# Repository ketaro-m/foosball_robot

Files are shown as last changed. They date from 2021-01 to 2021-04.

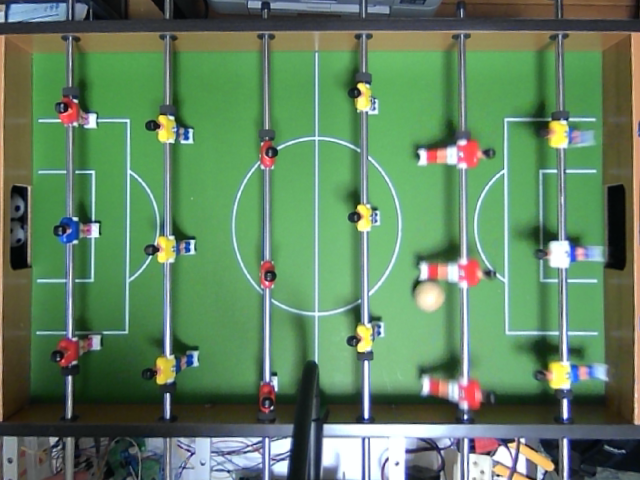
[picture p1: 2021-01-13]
img/board.png

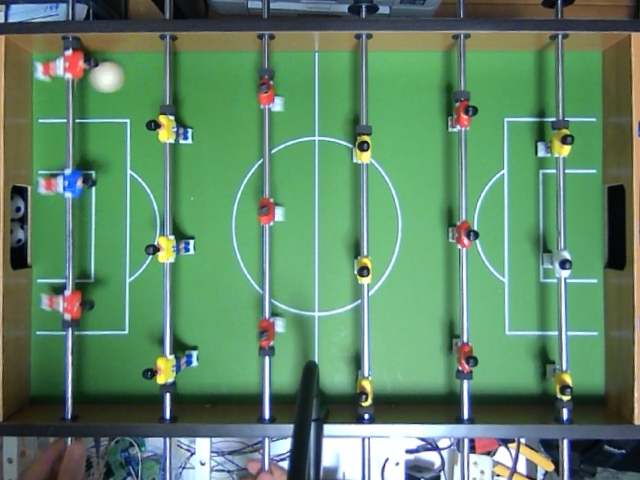
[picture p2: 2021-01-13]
img/board2.png

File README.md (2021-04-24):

# Foosball Robot
This is a vision controlled foosball table. The camera above the table processes the image and tracks the ball's position. The Arduino receives that information via ROS communication and control six stepper motors simultaneously; linear and rotation axes for three bars.



# Demo
Dome video is here. &rarr; https://youtu.be/knL-YN4Qc_c

# Environment

## Hardware
- [Arduino Mega 2560](https://store.arduino.cc/usa/mega-2560-r3)
- [L6470 stepper motor driver](https://www.st.com/en/motor-drivers/l6470.html) ([datasheet](https://www.st.com/resource/en/datasheet/l6470.pdf))  
... details are on [the report](https://github.com/ketaro-m/foosball_robot/blob/main/docs/report.pdf)

### Circuit diagram

## Software

- Ubuntu 18.04
- ROS Melodic Morenia

### ROS packages

- [uvc_camera](http://wiki.ros.org/uvc_camera)
- [usb_cam](http://wiki.ros.org/usb_cam) &larr; use this package instead of uvc_camera if uvc_camera doesn't support your camera driver's pixel format.
- [camera_calibration](http://wiki.ros.org/camera_calibration)
- [image_proc](http://wiki.ros.org/image_proc)
- [cv_brigde](http://wiki.ros.org/cv_bridge)
- [opencv_apps](http://wiki.ros.org/opencv_apps)
- [rosserial](http://wiki.ros.org/rosserial) (See [*Appendix A*](#appendix-a:-installing-rosserial) for installation)
- [rqt_image_view](http://wiki.ros.org/rqt_image_view)
- ([Joy](http://wiki.ros.org/joy)) &larr; Joy stick controll mode (see [joy branch](https://github.com/ketaro-m/foosball_robot/tree/joy))

### System diagram


# 1. Camera Calibration

## ROS Wiki
- [camera_calibration](http://wiki.ros.org/camera_calibration)
- [How to Calibrate a Monocular Camera](http://wiki.ros.org/camera_calibration/Tutorials/MonocularCalibration)

First, download the checker board ([check_7x6_27mm.pdf](http://wiki.ros.org/turtlebot_kinect_arm_calibration/Tutorials/CalibratingKinectToTurtleBotArm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)) and run the calibration program. Move the checker board around in the camera view.

```bash
$ ls /dev/ | grep video # check the device name

# run calibration programs (in different terminals)
$ roscore
$ rosrun uvc_camera uvc_camera_node _device:=/dev/video1
$ rosrun camera_calibration cameracalibrator.py --size 7x6 --square 0.027 image:=/image_raw
```

 

Then extract the gz file and place the yaml file in the appropriate directory.

```bash
# make camera.yaml
$ mkdir camera_calibration; cd camera_calibration
$ mv /tmp/calibrationdata.tar.gz ./
$ tar -xvzf calibrationdata.tar.gz
$ mv ost.yaml camera.yaml
$ vi camera.yaml 
# rewrite "camera_name: narrow_stereo" -> "camera_name: camera", 
#         "camera_model: plumb_bob" -> "distortion_model: plumb_bob"
```

Finally, check the result

```bash
$ roscore
$ rosrun uvc_camera uvc_camera_node _device:=/dev/video1 _camera_info_url:=file://$PWD/camera_calibration/camera.yaml
$ rosrun image_proc image_proc
$ rqt_image_view
```

or run this launch file (yet, need to modify the absolute path to camera.yaml in line 4)

```bash
$ roslaunch launch/calibration_demo.launch # use "calibration_demo_usb.launch" instead for usb_cam package 
```

  

# 2. Ball Tracking

### 1. Check the pixels of the fields.

After establishing the camera nodes, open rqt_image_view and select /image_rect_color. Then click the top-left and bottom-right points and check their pixel x, y values with echoing /image_rect_color_mouse_left.

```bash
$ roslaunch launch/track_ball.launch # use "track_ball_usb.launch" instead for usb_cam package
$ rqt_image_view # select /image_rect_color
$ rostopic echo /image_rect_color_mouse_left
```
Fill these values in `scripts/hsv.py` and `scripts/track_ball_demo.py`.

```Python
field_area = [[33, 50], [605, 405]] # [[top-left x,y], [bottom-right x, y]]
```

### 2. Optimize HSV value

In order to track only the ball, you have to optimize the HSV value of the mask filter.  
To do so, save a camera view image using the save button of the rqt_image_viewer, and run `scripts/hsv.py` with the image.

```bash
$ python scripts/hsv.py [image file name]
```
Click the ball in the "hsv" image window, and check the HSV value which is printed on the terminal. 

 
<br />

Lastly, to check if the ball is correctly tracked, fill the hsv_lower and hsv_upper values obtained above and run `scripts/track_ball_demo.py`. Looking at the result, you might have to modify hsv values and filter sizes of image processings.

(track_ball_demo.py)

```Python
# obtain from hsv.py
hsv_lower = np.array([20, -10, 100])
hsv_upper = np.array([50, 64, 300])
median_size = 7      # filter size for median filter
morpho_size = 13     # filter size for morphology processing
```
In terminal, run the following commands.

```bash
$ roslaunch launch/track_ball.launch
$ python scripts/track_ball_demo.py
```

 

### 3. Publishing ROS topic
Finally, publish the ball position as a ROS topic, which will be subscribed by the Arduino. `scripts/ball_position_publisher.py` conducts the entire image processing of the previous sections and publishing ROS topic `/ball_position (opencv_apps/Circle)`. This script will be used as the final form of this section.  
Fill the parameters in line 11~18 and confirm that the ball position is correctly published.

```bash
$ roslaunch launch/track_ball.launch # use "track_ball_usb.launch" instead for usb_cam package
$ python scripts/ball_position_publisher.py
$ rostopic echo /ball_position
```

# 3. Let's play!
Now you've prepared all pieces. Kickoff is almost there!  

After writing "sketchbook/L6470_SPI_stepMoter_sketch/L6470_SPI_stepMoter_sketch.ino" into the Arduino Mega, launch the uvc_camera node and rosserial node by the following command.

```bash
$ roslaunch launch/stepper_camera_driver.launch # use "stepper_camera_driver_usb.launch" instead for usb_cam package
```
Once the nodes have been successfully launched, the motor positions will be initialized like this.

 

The last thing you have to do is launching the image processing node. If you start running this program, the whole ROS pipeline is established and the robot starts moving.

```bash
$ python scripts/ball_position_publisher.py
```
Enjoy fighting!

 

# Appendix
## *Appendix A: Installing rosserial*

First, you need to install the ros packages.

```bash
$ sudo apt install ros-melodic-rosserial
$ sudo apt install ros-melodic-rosserial-arduino
```

Second, go to the *libraries* directory below the installed Arduino folder, and run the following setup script which is given by the rosserial package.

```bash
$ cd ~/arduino-1.8.13/libraries
$ rosrun rosserial_arduino make_libraries.py .
$ ls | grep ros_lib  # check if it's successfully installed
ros_lib
```

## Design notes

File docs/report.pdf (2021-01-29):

## Foosball Robot

## 03-190294 村上 恵太郎

01/29/2021

## 1 概要

Foosball(通称テーブルサッカー) の対戦相手となるロボットを制作した．Web カメラで読み込んだ画像からボー ルの位置を認識し，その結果に基づいてモータを制御してバーを動かしている．以下にデモ動画を作成した．

✓ | ✏
https://youtu.be/knL-YN4Qc_c ✒ | ✑
✓ また，完成したソースコードは以下のリポジトリに置いてある． | ✏
https://github.com/ketaro-m/foosball_robot ✒ | ✑

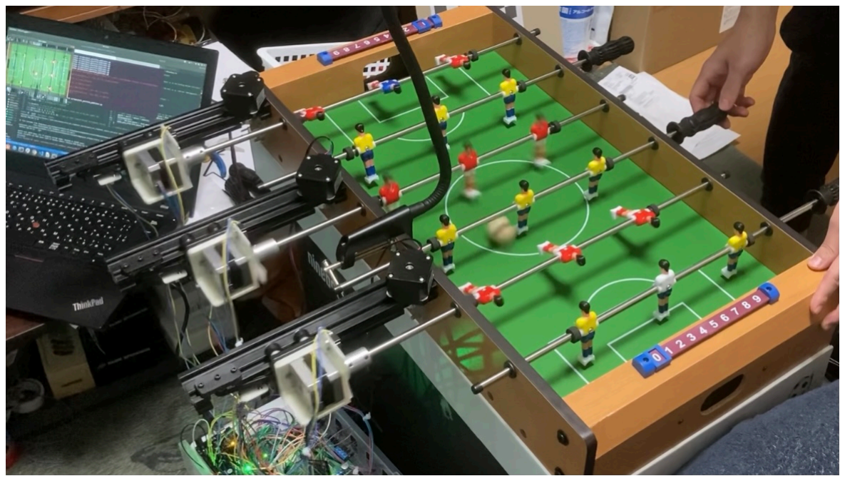
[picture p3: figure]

図 1: 作品の全体像

## 2 実行環境

### 2.1 ハードウェア

ハードウェアは補遺 A に記載した部品表のものを使用した．

### 2.2 ソフトウェア

- Ubuntu 18.04
- ROS Melodic Morenia

ROS packages

- uvc camera (http://wiki.ros.org/uvc_camera)
- camera calibration (http://wiki.ros.org/camera_calibration)
- image proc (http://wiki.ros.org/image_proc)
- cv bridge (http://wiki.ros.org/cv_bridge)
- rosserial (http://wiki.ros.org/rosserial)
- rqt image view (http://wiki.ros.org/rqt_image_view)

## 3 動作原理

台の真上に設置した Web カメラで盤面の画像を読み込み，色抽出をベースとした画像処理を施すことによって ボール位置を認識し，その結果を Arduino が受け取って 6 つ (3 つのバーそれぞれにつき並進と回転) のステッピ ングモータを制御することによってボールを打ち返す．これを 10 fps のサイクルで繰り返すことによって，ボー ルに素早く追従する．
この全体像を ROS ノードの構成図で表すと以下のようになる．

図 2: ROS ノード

## 4 動作結果

まず，L6470 SPI stepMoter sketch.ino (https://github.com/ketaro-m/foosball_robot/blob/main/sketchbook/L6470_SPI_stepMoter_sketch/L6470_SPI_stepMoter_sketch.ino) をArduinoに書き込む．次に，以下にあるように launch/stepper camera driver.launch (https://github.com/ketaro-m/foosball_robot/blob/main/launch/stepper_camera_driver.launch) を実行してカメラノードなどの複数の ROS ノードを立ち上げた後，最後に scripts/ball position publisher.py (https://github.com/ketaro-m/foosball_robot/blob/main/scripts/ball_position_publisher.py) を
✓
実行して画像処理ノードを立ち上げると，図 2 にあるようなパイプラインが繋がって全体が動くようになる．

✏

$ roslaunch launch/stepper camera driver.launch
$ python scripts/ball position publisher.py
✒ | ✑

## 5 制作過程

### 5.1 ハードウェア設計

既製品の Foosball 台を使用し，それに合うように部品を選定して組み合わせた．リニアモジュールとステッピ ングモータを接続する部分，ゼロ点 (モータ制御のセクションで説明する) 用のマイクロスイッチを取り付ける部 分は 3D プリンタを用いて作成した．

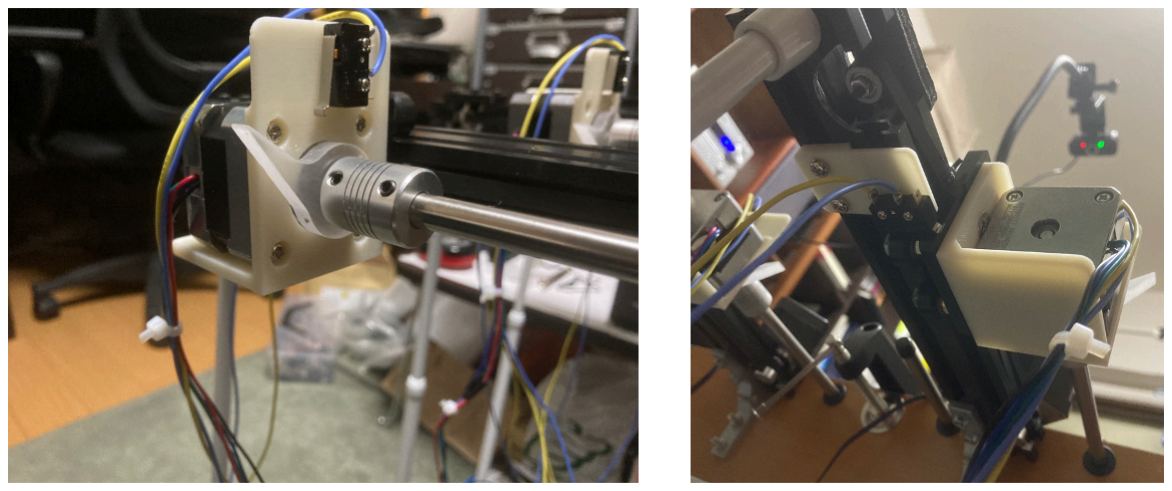
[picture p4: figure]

図 3: 3D プリンタで作成した部品

### 5.2 画像処理

### 5.2.1 カメラキャリブレーション

Web カメラから直接入ってくる画像にはレンズ歪みがあるので，これを補正する内部パラメータを求める必要が ある．このためのプログラムは用意されているため，以下のサイトに従ってチェッカーボードをカメラの前で動か すことで，画像のように補正することができる．詳細な手順は，README.md(https://github.com/ketaro-m/

foosball_robot/blob/main/README.md) (https://github.com/ketaro-m/foosball_robot/blob/main/README.md) に記載している．

- camera calibration (http://wiki.ros.org/camera_calibration)
- How to Calibrate a Monocular Camera (http://wiki.ros.org/camera_calibration/Tutorials/

MonocularCalibration) (http://wiki.ros.org/camera_calibration/Tutorials/MonocularCalibration)

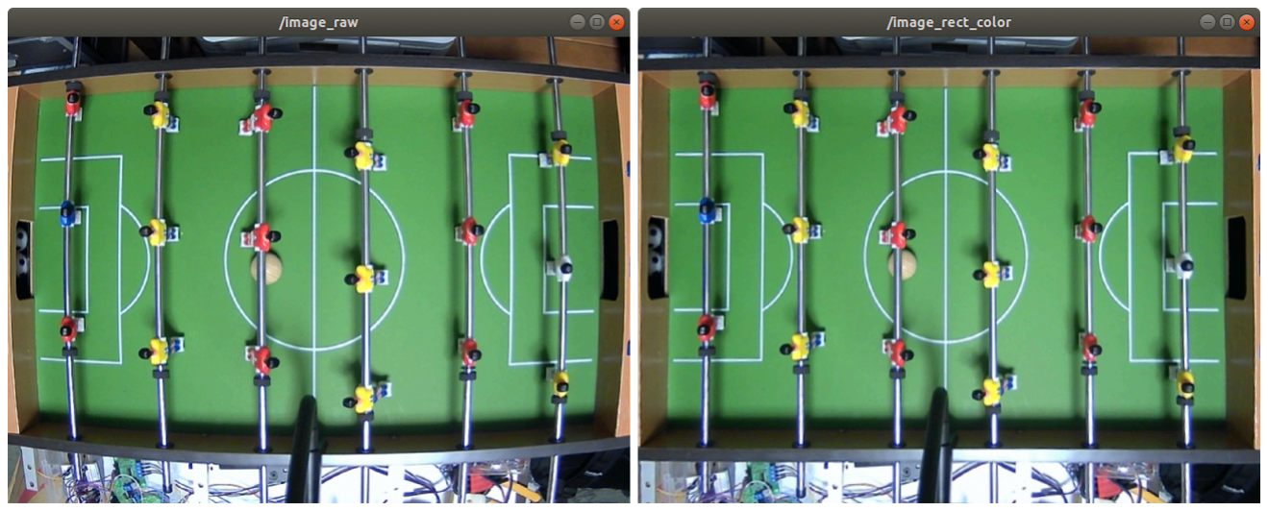
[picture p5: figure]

図 4: キャリブレーション結果

### 5.2.2 ボール検出

ボールの検出には HSV カラーフィルタを用いる．
画像処理の一連の流れは以下の画像の通りで，まず初めにフィールド内 (画像内でのフィールドのピクセルは事前 に設定しておく) に HSV フィルターをかけ，特定の HSV 値の領域を抽出する．次に，メジアンフィルタ，膨張・ 収縮処理を施すことによって，ノイズ除去とボール領域のクロージングを行う．最後に画像中の最大領域を取得す ることによって，ボールの領域のみを検出する．

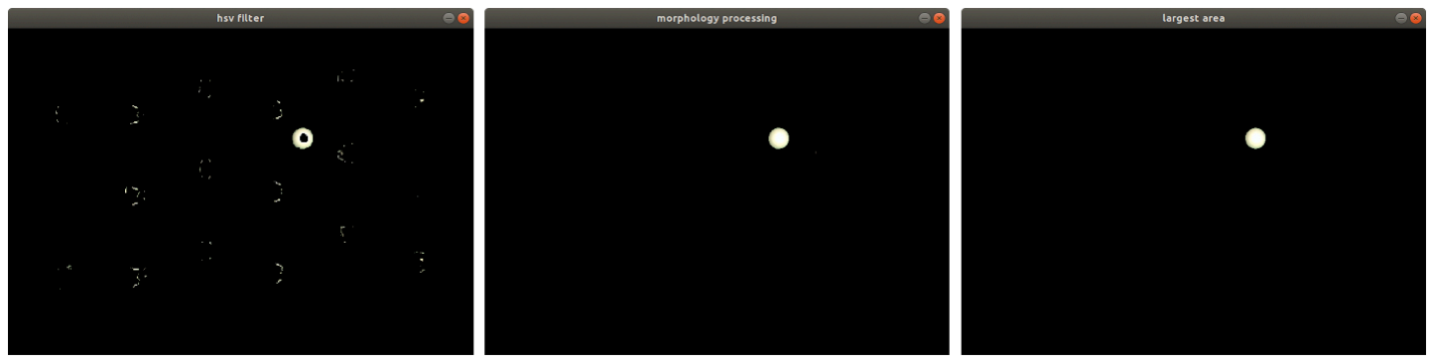
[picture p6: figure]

図 5: 画像処理

ボールの HSV 値は適切に設定しておく必要がある．しかし，環境によって光の当たり具合が若干異なり適切な HSV 値が変わってしまうため，このチューニング用のプログラムも作成した． カメラノードを立ち上げた状態で script/hsv.py (https://github.com/ketaro-m/foosball_robot/blob/main/scripts/hsv.py) を実行すると画像が表示され，ボールをクリックするとそのピク セルの HSV 値が得られる．このプロセスを何回か行ったり，ボール内の様々なピクセルを選択することで，適切

な HSV 値の領域をチューニングする．
この値を scripts/ball position publisher.py (https://github.com/ketaro-m/foosball_robot/blob/main/scripts/ball_position_publisher.py) のプログラム上部に設定して以下のようにプログラムを立ち上げる と，画像のように適切にボール位置を検出することができていることが分かる．また，このプログラムはその座 標を ROS トピック (/ball position (opencv apps/Circle 型)) として publish する役割も担っている．

こちらも，詳細な手順は，README.md(https://github.com/ketaro-m/foosball_robot/blob/main/README.

md (https://github.com/ketaro-m/foosball_robot/blob/main/README.md)

✓
) に記載している．

✏

$ roslaunch launch/track ball.launch
$ python scripts/ball position publisher.py
$ rostopic echo /ball position
✒ | ✑

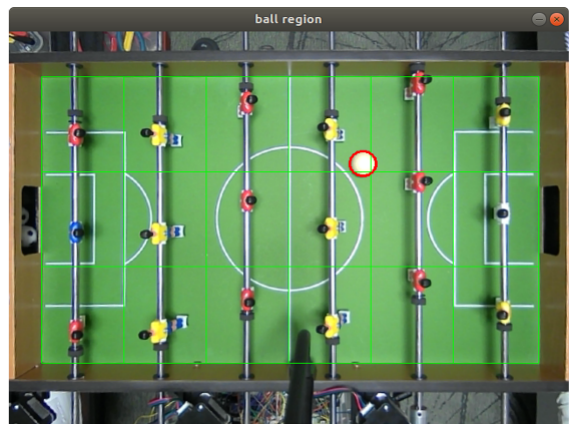
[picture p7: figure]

図 6: 検出結果

### 5.3 モータ制御

ステッピングモータの制御には，L6470 というチップの乗ったモータドライバを使用した．SPI 通信という方 式が取られ，8bit ごとにデータを区切って送信することで，データシート (https://www.st.com/resource/en/datasheet/l6470.pdf) (https://www.st.com/resource/en/datasheet/l6470.pdf) に載っている様々なコマンドを送って制御できる．これを実現する Arduino スケッチの

ライブラリは，このブログ (http://spinelify.blog.fc2.com/blog-entry-41.html) に載っているものを使用 した．
複数のモータを制御するためには，モータドライバをデイジーチェイン接続する必要がある．デイジーチェイン接続

とは，図 7 にあるように (このブログ (https://garchiving.com/control-multiple-motors-with-arduino/) から引用した)，複数 byte を順々に押し出してそれぞれのモータドライバに所望の byte 値を書き込む方式である． このデイジーチェイン接続を考慮した複数モータの制御ライブラリは存在しなかったため，上述のライブラリを 参考にしながら，全てのライブラリを書き直す作業を要した．これにより，デイジーチェインという直列の通信方 法であっても，Arduino スケッチのメインプログラム内では，特定のモータのみを特定のコマンドで駆動するよ うな形式でプログラムできるようにした．
今回の作品ではモータをデフォルト値よりもかなり高速に動かす必要があった．これはモータドライバのあるレ ジスタ値を設定することで実現できるのだが，その値に伴って電圧値も適切に設定する必要があった．また，モー タを速く動かしすぎると脱調を起こしてしまう．これを防ぐためにも，各種レジスタ値をチューニングし，加速度 やその立ち上がりの角度を適切に設定する作業が必要であった．この適切な値はモータの数を増やす度に若干変 更されるため，その都度チューニングする必要があった． どうしても脱調を起こしてしまうことは防ぎきれず自己位置がずれてしまう，また，ボールがプレイヤーに強く当 たるとモータが逆方向に回転してずれてしまう．これを補正するためには，図 3 にあるようにマイクロスイッチに よるゼロ点を用意した．原理としては，脱調が検出されたら，そのモータを脱調復帰モードに切り替えてマイクロ

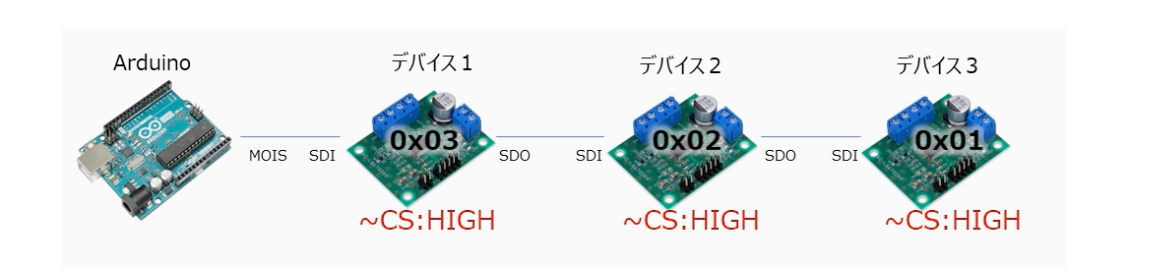
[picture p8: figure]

図 7: デイジーチェイン接続

スイッチが押される位置まで動かし，押された瞬間にモータドライバの位置レジスタの値を所定の値にリセットす るというメカニズムである．また，脱調検出がされなくても，スイッチが押される位置にモータが来たときは位 置をリセットし，自己位置がずれてしまったが脱調検出がなされなかった場合にも定期的に修正するようにした． 脱調とは，モータが機械的に入力パルスに追従できず，ストール (失速) する現象である．これは，モータの起電 力という形で電気的に検出でき，今回使用したモータドライバにはエラー検知用のレジスタという形で組み込ま れていた．よって，これらを Arduino の入力ピンに結線して監視することで，脱調検出を可能とした．この検出 判定の閾値などのパラメータは，何回か試してみて決定する必要があった．

Arduino スケッチの概要

- L6470 SPI stepMoter sketch.ino (https://github.com/ketaro-m/foosball_robot/blob/main/sketchbook/L6470_SPI_stepMoter_sketch/L6470_SPI_stepMoter_sketch.ino) ← メインプログラム
- L6470 commands.ino (https://github.com/ketaro-m/foosball_robot/blob/main/sketchbook/L6470_SPI_stepMoter_sketch/L6470_commands.ino) ← モータコマンドライブラリ
- L6470 commands multi.ino (https://github.com/ketaro-m/foosball_robot/blob/main/sketchbook/L6470_SPI_stepMoter_sketch/L6470_commands_multi.ino) ← モータコマンドライブラリ (デイジーチェイン対応)
- foosball commands.ino (https://github.com/ketaro-m/foosball_robot/blob/main/sketchbook/L6470_SPI_stepMoter_sketch/foosball_commands.ino) ← ゲーム操作コマンドのライブラリ

メインプログラム (L6470 SPI stepMoter sketch.ino) は，同じディレクトリ内にあるライブラリをインポートす る形で利用している．まずセットアップでは，各種ピンの設定，SPI 通信の立ち上げ，ROS ノードの立ち上げな どを行い，メインループの中で恒常的に脱調検出ピン，ゼロ点ピンの監視を行っている．さらに，画像処理ノー ドによって publish されたボール位置を subscribe しており，その結果に基づいたコマンド操作をして，バーを操 縦している．
バー操縦のコマンドは比較的シンプルで，まず，図 6 にあるようにフィールドを分割することで，ボールが相手 側にあるか自分側にあるかを判別し，相手側にあった場合はディフェンス，自分側にあった場合はオフェンス動 作をする．ディフェンスの場合は，横方向はボール位置に追従するようにスライドし，ボールよりも後ろにいる プレイヤーは足でボールを止められるようにバーを回転する．ボールよりも前のプレイヤーは攻撃に備えて足を あげておく．オフェンスの場合は，ボール位置にいるバーはキックモーションを行い，それよりも後ろはディフェ ンスと同じ要領で防御の構えをし，それよりも前にいるバーは後ろから来るボールの通路を空けるように構える． 基本的にはこのようなコマンドは全てモータの回転角を指定することで実現でき，ボール位置の publish と同じ周 波数，つまり 10 fps でモータの回転角を上書きしていくようなサイクルで指示を出していくが，キックモーショ ンは 1 回のサイクルよりも長いサイクルを要する．この場合や，脱調検出がされたことによって脱調復帰モードに なっているモータには指示がいかないように，特定のモータにだけコマンド指示が送られるように工夫した．具 体的には，グローバル変数として 6bit の変数を用意し，各 bit にそれぞれのモータの状態フラグを表現して，そ の情報も含めてモータに指示が送られるように工夫した．各モータフラグを配列として表現するとポインタの受 け渡しなどが煩雑になったが，このように int 型の変数を 2 進数と見なして受け渡すことで，プログラムを簡潔に したり，メモリの節約をすることができた．

## 6 苦労したこと，反省，感想

スターリングエンジン設計演習を通して機械設計や加工は経験したが，ソフトウェアや電子部品も含めて一人 で設計する経験はほとんど初めてだった．自分で加工した部品は少ないが，データシートを正しく読み，適切な 部品を選定する過程は非常にためになった．
ハードウェアを含んだものだと，理論上は正しく動くはずでも実機では動作しないということが多々起こり，ま たそのデバッグも大変だった．例えば，モータを複数に増やすと電圧・電流が足りなくなって動作をしなくなる， Arduino Nano ではメモリが少なく，ROS ノードを立てるような処理を加えるとメモリが圧迫されて動作が不安 定になる，といったバグは発見するまでに時間を要した．しかし，理論を学んだだけでは気づけないようなバグ を身を持って体験できたのは貴重な経験だったと思う．
この制作過程で最も大変だったのは，複数のモータを適切に制御することだった．特に，今回は非常に素早く動 かす必要があったので，モータの特性から考えて各種のパラメータを調整する過程が大変だった．また，複数の モータにした途端に動かなくなったり，計算のオーバーフローが起きていたり，突き詰めていけば必ずどこかに特 定の原因があるものだが，それを見つけるまでに多くの時間を費やしてしまった．しかしながら，こうしたエラー は体系的に学べるものではなく，このように逐一経験していくことでしか学べないので，今後の糧になると思う． 当初の題目は「FC DQN」であったように，目標は強化学習を用いてモータ制御も学習させることだったが，上 述のモータ制御に時間がかかってそこまで辿り着くことはできなかった．モータ制御のセクションで説明したよ うなルールベースのプログラムでも対戦相手としては楽しめるものになったし，1ヶ月強の制作期間で作るものと しては及第点だと思うが，せっかくなら学習にも着手したかった．この辺りは，制作のスケジュールの問題であ り，反省して次に活かせるポイントである．例えば，部品の発注は到着するまでに時間がかかるから早めに済ま すなどの優先順位をつけることはもちろん，期限までに小さなマイルストーンを置き，小さなステップに分解し ながら進めることで進捗管理やプラン B への切り替え判断を迅速にするなどの工夫も必要だと感じた．この辺り は，エンジニアリングの世界では重要なことであると思うので，今後に生かしていきたい．

### お願い

総じて自主プロは非常に良いプログラムだと思いますが，費用の全てが学生の自己負担であることは，この演 習の唯一の欠点だと思います．僕が上述のように経験できたデバッグ作業は，ハードウェアを積極的に使うことで 得られるものであるし，僕もその観点から費用を捻出することにためらいはなかっのびですが，金銭的な問題か ら制作物を制限してしまう学生も少なからずいるのではないかと思います．少額であっても学生の学びの質を高 めることになり，自主プロがより良い演習になると思うので，制作費用の支援の検討をしていただければ後輩の ためになると思います．

謝辞

オンラインという難しい状況の中，多くの先生方のご協力のもと，この作品を完成させることができました． コンセプト段階から相談に乗っていただけた岡田先生，モータ制御や機械設計についてアドバイスをくださった 浅野先生，3D プリンタの印刷を手伝っていただいた西川先生には特に感謝を申し上げます． その他，相談に乗ってくださった先生方，学科同期の皆さん，ありがとうございました．

## 補遺 A 部品表

以下に使用した部品の一覧を記載する．(部品名にハイパーリンクを付与している．)

部品名 | 個数
Foosball 台 (https://blog.jp.flyingtiger.com/item/zebrajapan-flyingtigercopenhagen-1600421636936-apparelcloud.productclass-5a3e3637-a5a9-4a0c-a2f3-f4ed53f3d1e7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) | 1
木球 | 1
ThinkPad (学科 PC) | 1
Arduino Mega (https://store.arduino.cc/usa/mega-2560-r3) | 1
AC アダプタ (24V 2.7A) (https://akizukidenshi.com/catalog/g/gM-06962/) | 1
DC ジャック端子変換 (https://akizukidenshi.com/catalog/g/gC-08849/) | 1
ブレッドボード，各種ジャンパピン
ステッピングモータリニアモジュール (https://www.banggood.com/HANPOSE-HPV2-Linear-Guide-Set-Openbuilds-V-Linear-Actuator-Effective-Travel-100-400mm-Linear-Module-with-17HS3401S-Stepper-Motor-p-14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) | 3
ステッピングモータ 42SHD4002-24B (https://akizukidenshi.com/catalog/g/gP-14604/) | 3
L6470 ステッピングモータドライバ (https://akizukidenshi.com/catalog/g/gK-07024/) | 6
M3×6 ねじ (ステッピングモータ固定用) | 12
カップリング (https://www.amazon.co.jp/-/en/gp/product/B07JL1QYLS/ref=ppx_yo_dt_b_asin_title_o00_s00?ie=UTF8&psc=1) | 3
ブラケット (https://www.monotaro.com/p/2173/7494/) | 3
M5 六角ナット, (https://www.monotaro.com/p/0552/8722/) ワッシャー (https://www.monotaro.com/p/0552/9772/) | 3
M5×20 皿木ネジ (F oosball 台とリニアモジュールの接続用) | 3
M5×8 皿頭小ねじ (リニアモジュールと 3D プリンタ部品の接続用) (https://www.monotaro.com/p/0550/8711/) | 12
マイクロスイッチ (https://akizukidenshi.com/catalog/g/gP-14659/) | 6
M2×12 ねじ，ナット (マイクロスイッチ固定用) | 12
M4×10 ねじ (マイクロスイッチ台座固定用) | 6
M3×6 いもねじ (ステッピングモータ軸と 3D プリンタ部品の固定用) | 6
USB カメラ (https://www.amazon.co.jp/-/en/Network-Computer-Flexible-Recording-Conference/dp/B08F7TR97T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) | 1
カメラスタンド (https://www.amazon.co.jp/-/en/Webcam-Adjustable-Tabletop-Camera-Logitech/dp/B071P5QRQ1) | 1

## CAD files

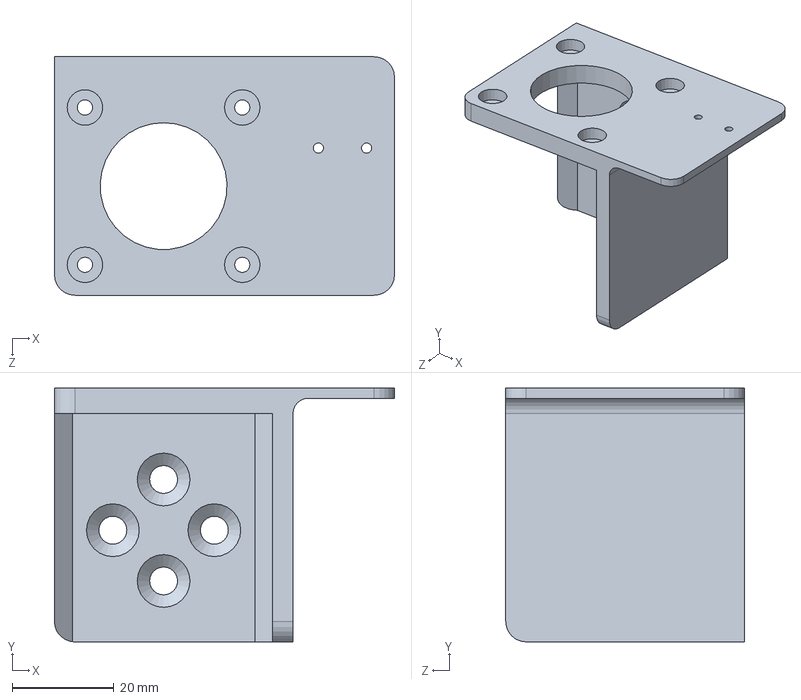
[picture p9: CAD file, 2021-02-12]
cad/stepper_bracket_v2.SLDPRT
67.0 x 50.0 x 47.0 mm

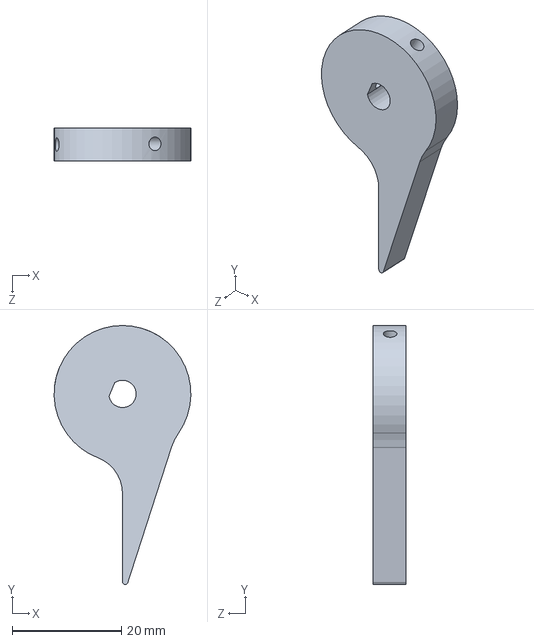
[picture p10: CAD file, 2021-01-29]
cad/pin_v3.SLDPRT
25.0 x 47.3 x 6.00 mm

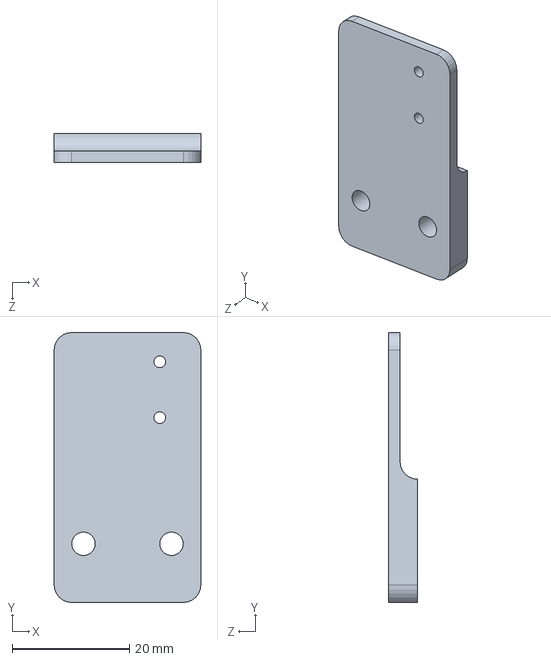
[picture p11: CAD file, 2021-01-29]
cad/switch_base.SLDPRT
25.0 x 46.0 x 5.00 mm

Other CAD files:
cad/stepper_bracket.SLDPRT
cad/pin_v3.STL
cad/stepper_bracket.STL
cad/stepper_bracket_v2.STL
cad/switch_base.STL

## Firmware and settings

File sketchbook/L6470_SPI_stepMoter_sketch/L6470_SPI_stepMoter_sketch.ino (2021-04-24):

#include <SPI.h>
#include <ros.h>
#include <opencv_apps/Circle.h>
#include <std_msgs/Int32MultiArray.h> // to publish pin values
ros::NodeHandle nh;
// #include "L6470_commands.ino"
// #include "L6470_commands_multi.ino"
// #include "foosball_commands.ino"

// number of motors
#define N 6
// define pins
#define PIN_SPI_MOSI 51
#define PIN_SPI_MISO 50
#define PIN_SPI_SCK 52
#define PIN_SPI_SS 53
#define PIN_BUSY 9
const int ERROR_PIN[N] = {2,3,4,5,6,7}; // digital pins
const int RESET_PIN[N] = {54,55,56,57,58,59}; // analog pins A0,...,A5 
const int PSEUDO_ERROR_PIN[3] = {62, 63, 64}; // manually trigger error recovery motionn
// parameters according to this machine environment
int ROT = 200*pow(2, 7); // steps per 1 rotation
int STROKE = 40; // stroke[mm] per 1 rotation

long param[N]; // array to get and store register values such as abs_pos, speed, etc.
/* position array to control motors */
long pos[N] = {0, 0, 0, 0, 0, 0};
long pos_copy[N] = {0, 0, 0, 0, 0, 0}; // copy pos because distang2pos change its values.
uint8_t non_error_motors = 0b111111; // mth bit is 0 if the mth motor steps out
uint8_t error_motion = 0b000000; // if mth motor is in error recovery motion or not (in order to avoid double command sending)
// long error_recovery_speed = 0x6000; // motor speed of error recovery motion.
long error_recovery_speed[N] = {0x6000, 0x6000, 0x6000, 0x3000, 0x3000, 0x3000}; // motor speed of error recovery motion.
long reset_pos[N] = {0, 0, 0, 0, 0, 0}; // set positions when the reset pin is pushed.
long reset_pos2[N] = {5, 5, 5, 10, 10, 10}; // positions to move just after touching reset pin in order to avoid touching pins forever

void stepper_cb(const opencv_apps::Circle& msg);
ros::Subscriber<opencv_apps::Circle> stepper_sub("ball_position", stepper_cb);
std_msgs::Int32MultiArray stepper_msg;
ros::Publisher stepper_pub("stepper", &stepper_msg);


void stepper_setup() {
  stepper_msg.data_length = N*3 + 2;
  stepper_msg.data = (int32_t *)malloc(sizeof(int32_t)*(N*3+2));
  for (int i = 0; i < N*3+2; i += 1) {
    stepper_msg.data[i] = 0;
  }

  nh.subscribe(stepper_sub);
  nh.advertise(stepper_pub);
}

/* publish the motors' state [abs_pos*6, error_pin*6, reset_pin*6, ball_position(x,y)] */
void stepper_publish_loop() {
  L6470_getparam_abspos(param, N);
  pos2distang(param);
  for (int i = 0; i < N; i += 1) {
    stepper_msg.data[i] = param[i];
    stepper_msg.data[i+N] = digitalRead(ERROR_PIN[i]);
    stepper_msg.data[i+N*2] = digitalRead(RESET_PIN[i]);
  }
  stepper_pub.publish(&stepper_msg);
}

/* subscribe ball_position and control stepper motors 
command() is in foosball_commands.ino. */
void stepper_cb(const opencv_apps::Circle& msg) {
  command((long)msg.center.x, (long)msg.center.y);
}

void setup()
{
  distang2pos(reset_pos);
  distang2pos(reset_pos2);
  // delay(1000);
  nh.initNode();
  stepper_setup();

  pinMode(PIN_SPI_MOSI, OUTPUT);
  pinMode(PIN_SPI_MISO, INPUT);
  pinMode(PIN_SPI_SCK, OUTPUT);
  pinMode(PIN_SPI_SS, OUTPUT);
  pinMode(PIN_BUSY, INPUT);
  for (int i=0; i<N; i+=1) {
    pinMode(ERROR_PIN[i], INPUT);
    /* use RESET PINs (analog pin) as digital pull down pins. */
    pinMode(RESET_PIN[i], OUTPUT);
    digitalWrite(RESET_PIN[i], HIGH);
  }
  // pseudo error pins
  for (int i=0; i<3; i+=1) {
    pinMode(PSEUDO_ERROR_PIN[i], OUTPUT);
    digitalWrite(PSEUDO_ERROR_PIN[i], HIGH);
  }
  //
  SPI.begin();
  SPI.setDataMode(SPI_MODE3);
  SPI.setBitOrder(MSBFIRST);
  digitalWrite(PIN_SPI_SS, HIGH);
 
  L6470_resetdevice(N); //reset all motors
  L6470_setup(0b111111);
  delay(3000);
  initial_setup();
}

unsigned long publish_timer = 0;
void loop(){
  unsigned long now = millis();

  if ((now - publish_timer) > 100) {
    stepper_publish_loop();
    publish_timer = now;
  }

  nh.spinOnce();
  delay(1);

  check_reset_pin();
  check_error_pin();
}

/* setup motors. */
void L6470_setup(uint8_t motors){
  long acc[N] = {0x500, 0x500, 0x500, 0x500, 0x500, 0x500};
  long dec[N] = {0x500, 0x500, 0x500, 0x500, 0x500, 0x500};
  long maxspeed[N] = {0x100, 0x100, 0x100, 0x100, 0x100, 0x100};
  long kvalhold[N] = {0x10, 0x10, 0x10, 0x80, 0x80, 0x80};
  long kvalrun[N] = {0x10, 0x10, 0x10, 0x80, 0x80, 0x80};
  long kvalacc[N] = {0x10, 0x10, 0x10, 0x80, 0x80, 0x80};
  long kvaldec[N] = {0x10, 0x10, 0x10, 0x80, 0x80, 0x80};
  L6470_setparam_acc(motors, N, acc);
  L6470_setparam_dec(motors, N, dec);
  L6470_setparam_maxspeed(motors, N, maxspeed);
  L6470_setparam_minspeed(motors, N, 0x01);
  L6470_setparam_fsspd(motors, N, 0x3ff);
  L6470_setparam_kvalhold(motors, N, kvalhold);
  L6470_setparam_kvalrun(motors, N, kvalrun);
  L6470_setparam_kvalacc(motors, N, kvalacc);
  L6470_setparam_kvaldec(motors, N, kvaldec);
  L6470_setparam_alareen(motors, N, 0x30); // alarm enable, stall detection
  L6470_setparam_stallth(motors, N, 0xff); // threshold for error detection (need tuning)
  L6470_setparam_ocdth(motors, N, 0xf);

  L6470_setparam_stepmood(motors, N, 0x07); //default 0x07 (1+3+1+3bit) : 1/2^n*1.8[deg] = 1step 
} 


/* functions to change distance[mm] or angle[degree] to steps(pos)*/
long dist2pos(long distance) {
  return ROT * distance / STROKE;
}
long ang2pos(long angle) {
  return ROT * (angle) / 360;
}
long pos2dist(long position) {
  return position * STROKE / ROT;
}
long pos2ang(long position) {
  return (position) * 360 / ROT;
}
void distang2pos(long *distang) {
  for (int i = 0; i < N; i += 1) {
    if (i < 3) {
      distang[i] = dist2pos(distang[i]);
    } else {
      distang[i] = ang2pos(distang[i]);
    }
  }
}
void pos2distang(long *position) {
  for (int i = 0; i < N; i += 1) {
    if (i < 3) {
      position[i] = pos2dist(position[i]);
    } else {
      position[i] = pos2ang(position[i]);
    }
  }
}

/* return true if the N lease bits (pointing at N motors) of uint8_t flag contains at least one 1 value.
this is for not sending unnecessary nothing commands. */
boolean checkflag(uint8_t flag) {
  return (flag << (8 - N)) > 0;
}


/* check reset pins and */
uint8_t check_reset_pin() {
  uint8_t reset_motors = 0b000000;
  for (int i = 0; i < N; i += 1) {
    if (digitalRead(RESET_PIN[i]) == 0) {
      reset_motors = bitFlip(i, reset_motors);
    }
  }
  uint8_t recovered_motors = ~(non_error_motors) & reset_motors; // motors which recovered from the error, not just touched reset pin 
  if (checkflag(reset_motors)) {  // in order to avoid unncessary nothing command.
    L6470_hardstop_u(reset_motors, N);
    L6470_setparam_abspos(reset_motors, N, reset_pos);
    L6470_goto(reset_motors, N, reset_pos2);
    if (checkflag(recovered_motors)) {
      L6470_resetdevice(recovered_motors, N);
      L6470_setup(recovered_motors);
      L6470_setparam_abspos(recovered_motors, N, reset_pos2);
    }
    L6470_resetdevice(reset_motors, N);
    L6470_setup(reset_motors);
    L6470_setparam_abspos(reset_motors, N, reset_pos2);
  }
  non_error_motors = non_error_motors | recovered_motors; // recover if from error recovery mode

  return reset_motors;
}

/* check error pins and change global non_error_motors flag. */
void check_error_pin() {
  // for (int i = 0; i < N; i += 1) {
  //   if (digitalRead(ERROR_PIN[i]) == 0) {
  //     non_error_motors = bitFlip2(i, non_error_motors);
  //   }
  // }
  // change above later
  for (int i = 0; i < 3; i += 1) {
    if (digitalRead(PSEUDO_ERROR_PIN[i]) == 0) {
      non_error_motors = bitFlip2(i+3, non_error_motors);
    }
  }
  //
  uint8_t error_motion_first = ~(non_error_motors) & ~(error_motion); // motors which were not in error recovery motion
  if (checkflag(error_motion_first)) {
    error_recovery_motion(error_motion_first, error_recovery_speed);
  }
  error_motion = ~(non_error_motors);
}

/*copying array a to b, n elements. */
void array_copy(long *a, long *b, int n) {
  for (int i = 0; i < n; i += 1) {
    b[i] = a[i];
  }
}

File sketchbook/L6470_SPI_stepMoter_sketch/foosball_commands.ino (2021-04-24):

/* commands for stepping motor */

long field_size[2] = {590, 345}; //[mm] (width, height)
long max_y = 80; //[mm] the stroke 
long player_size = field_size[1] / 3 - max_y;
uint8_t kick_motors = 0b000000; // if the rotate motor is in the kicking motion (3~5 bits)


/* judge which x-axis part of 6 (left:0, right 5) the ball is in. even:me, odd:opponent. */
int xIndex(long x) {
    int index = x / (field_size[0]/6);
    return index;
}
/* return bar position to place a player to y position. */
long y2pos(long y) {
    long y_tmp = y % (field_size[1] / 3);
    return min(max(y_tmp - player_size/2, 0), max_y);
}

void defense(long y, int x_index) {
    int motor_num = (x_index-1) / 2; // linear motor in the ball zone
    for (int i = 3; i > motor_num; i -= 1) {
        pos[i+3] = 45;
    } // forward than the ball possessing opposite
    for (int i = motor_num; i >= 0; i -= 1) {
        pos[i+3] = 75;
        pos[i] = y2pos(y);
    } // backward than the ball posessing opposit
    array_copy(pos, pos_copy, N);
    distang2pos(pos);
    uint8_t non_kick_motors = ~kick_motors & non_error_motors;
    L6470_goto_u(non_kick_motors, N, pos);
    array_copy(pos_copy, pos, N);
}

/* kicking motion */
void kick(uint8_t motors) {
    motors = motors & 0b111000; // for safety
    long take_back = ang2pos(45);
    long follow_through = ang2pos(130);
    L6470_goto_u(motors, N, take_back);
    L6470_goto(motors, N, follow_through);
}

void offense(long y, int x_index) {
    int motor_num = x_index / 2; // linear motor in the ball zone
    for (int i = 3; i > motor_num; i -= 1) {
        pos[i+3] = 30;
    } // forward than the kick bar
    for (int i = motor_num-1; i >= 0; i -= 1) {
        pos[i+3] = 90;
    } // backward than the kick bar
    pos[motor_num] = y2pos(y);
    if (checkBit(motor_num+3, kick_motors)==0) {
        kick_motors = bitFlip(motor_num+3, kick_motors);
    }
    uint8_t non_kick_motors = ~kick_motors & non_error_motors;

    array_copy(pos, pos_copy, N);
    distang2pos(pos);
    L6470_goto_u(non_kick_motors, N, pos);
    if (checkflag(kick_motors)) {
        kick(kick_motors);
        kick_motors = 0b0;
    }
    array_copy(pos_copy, pos, N);
}

void command(long x, long y) {
    y = field_size[1] - y;
    int x_index = xIndex(x);
    stepper_msg.data[N*3] = x;
    stepper_msg.data[N*3+1] = y;

    if (x_index % 2 == 1) {
        defense(y, x_index);
    } else {
        offense(y, x_index);
    }
}

/* motion when the error flags occur. Move rotation motor forward dir=1, linear motor backward*/
void error_recovery_motion(uint8_t motors, long *speed) {
    uint8_t rot_motors = motors & 0b111000;
    uint8_t lin_motors = motors & 0b000111;
    if (checkflag(rot_motors)) {
        L6470_run_u(rot_motors, N, 0, speed); // dir=0, backward, or to negative
    }
    if (checkflag(lin_motors)) {
        L6470_run_u(lin_motors, N, 0, speed); // dir=0, backward, or to negative
    }

}


void initial_setup() {
    uint8_t motors = 0b111111;
    long speed[N] = {0x2000, 0x2000, 0x2000, 0x2000, 0x2000, 0x2000};
    error_recovery_motion(motors, speed);
    /* until all motors have been reset. */
    while (checkflag(motors)) {
        uint8_t reset_pin = check_reset_pin();
        motors = motors & ~reset_pin;
    }
    long pos[N] = {30, 30, 30, 90, 90, 90};
    array_copy(pos, pos_copy, N);
    distang2pos(pos);
    L6470_goto(N, pos);
    array_copy(pos_copy, pos, N);
    L6470_busydelay(2000);
}

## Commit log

2020-12-07 add steper motor sample
2020-12-08 change basic step angle and move motors by distance and angle
2020-12-11 sample for overwrite, switch
2020-12-19 succeed simple multiple motor control
2020-12-22 get multiple motors params
2020-12-22 control motors with the same values
2020-12-22 control motors with each values
2020-12-24 basic move for all 6 motors + changed baudrate to 115200
2020-12-27 optimized kvals to these motors and add basic rosserial advertisement
2020-12-28 camera calibration
2020-12-29 change arduinor from nano to mega
2020-12-30 control motors by joy stick
2021-01-06 add util commands to control specific motors
2021-01-06 reset pin error recovery motion
    [L6470_SPI_stepMoter_sketch.ino]
2021-01-07 reset with dummy pins, not move by ball position
    [L6470_SPI_stepMoter_sketch.ino, L6470_commands_multi.ino]
2021-01-29 add cad data and report.pdf
    [pin_v3.SLDPRT, pin_v3.STL, stepper_bracket.SLDPRT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]
2021-02-12 modified stapper bracket
    [stepper_bracket_v2.SLDPRT, stepper_bracket_v2.STL]
2021-04-24 change rotate reset position
    [L6470_SPI_stepMoter_sketch.ino, foosball_commands.ino]
